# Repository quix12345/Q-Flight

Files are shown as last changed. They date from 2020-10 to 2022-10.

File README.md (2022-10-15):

# Q-Flight Quadrotor

#### Descirpition
Q-Flight is a fully functional quadrotor system which was based on STM32 F411 & FreeRTOS. It includes the flight controller, ground station, Unity simulations and 3D printing model...

#### Q-Flight Overview

Q-Flight was the last project I've done in my high school times. It include the remote controller, flight control system based on STM32 F4, and related softwares... Click the video and see what Q-Flight got ! 
Video Download: [link](https://github.com/quix12345/Q-Flight/blob/master/qflight/quadrotor.mp4)
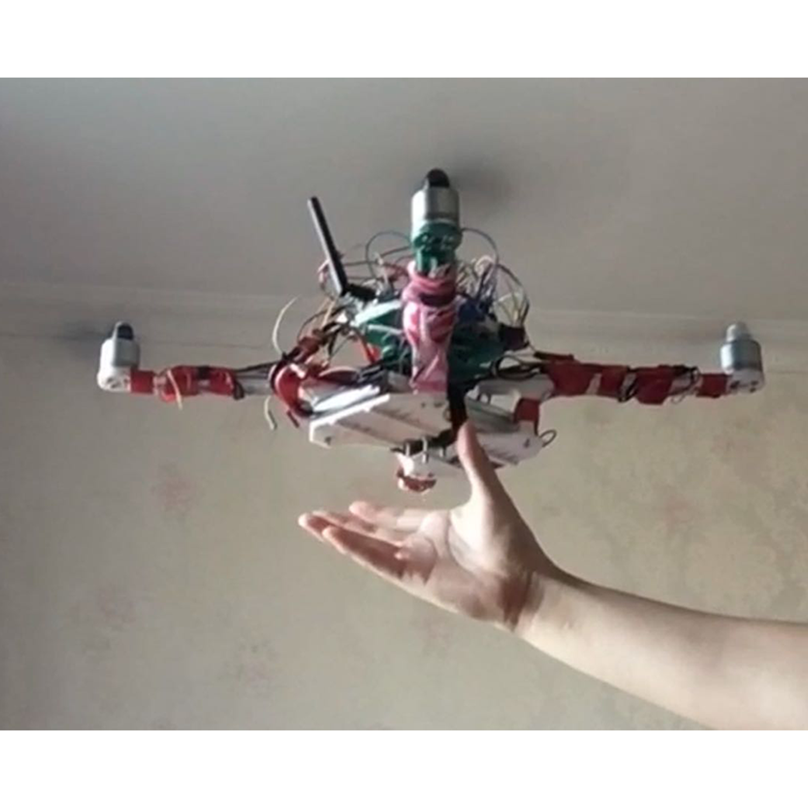
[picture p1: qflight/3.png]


#### Flight Controller

For the Q-Flight controller, a range of sensors was used, for instance the barometer and GPS are combined for the navigation and position control in outdoor, while laser lidar and optical flow sensor was responsible for the indoor positioning. By using Mahony algorithm as the core for calculating the attitude of the quadrotor from accelerometer and gyroscope, thus the internal Strapdown Inertia Navigation System will gain sufficient infomation to control its altitude and position. FreeRTOS is also used to make the whole system run at a higher speed. In addition to the core control system, GNSS and GPRS are also added to send back flight data to the back-end server through socket to monitor the flight even in case of remote control failure. 

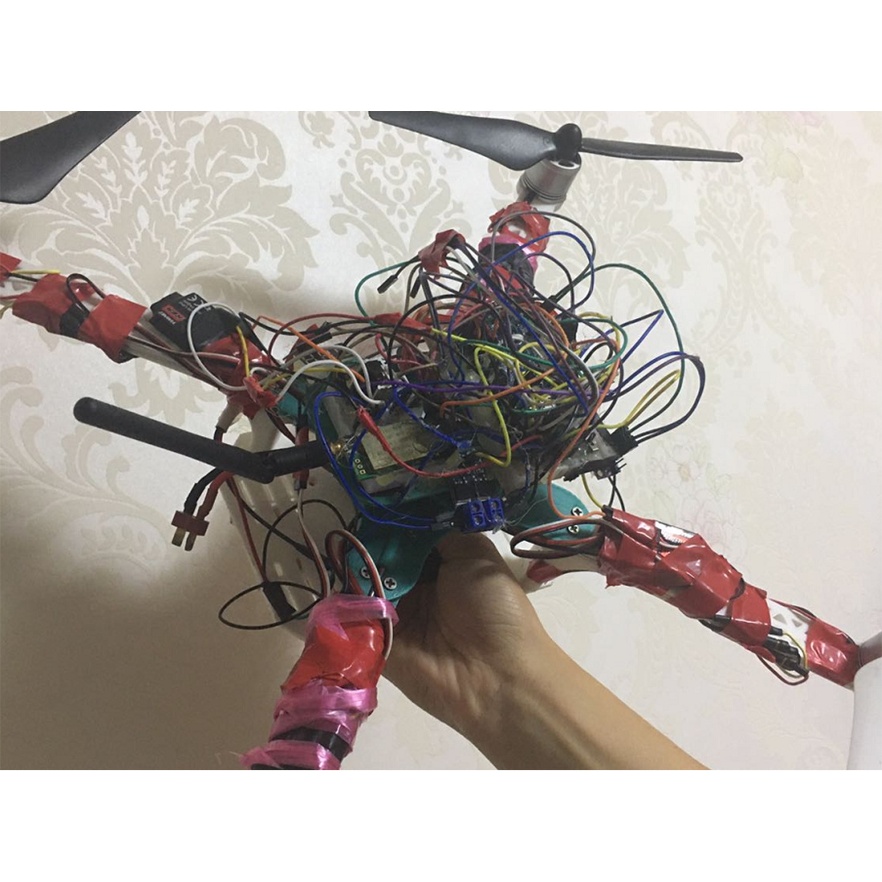
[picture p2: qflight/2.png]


#### Remote Control

The Remote Control use implemented by using wireless USART through LORA protocols which has achieve over  2100km as its valid remote control distance through air. The Q-Flight remote communication protocol supports the control of the quadrotor, transporting the quadrotor's status, change values in Flash, customize PID controllers, transmitting large amount of information, sensor calibration, etc. The protocol received by quadrotor starts with '0xC8' and end with '0xC9' , while the protocol received by the ground staion was start with double  '0xC8' and end with double '0xC9'. The hardware and coding system was proved to be highly reliable during several tests in Q-Flight.

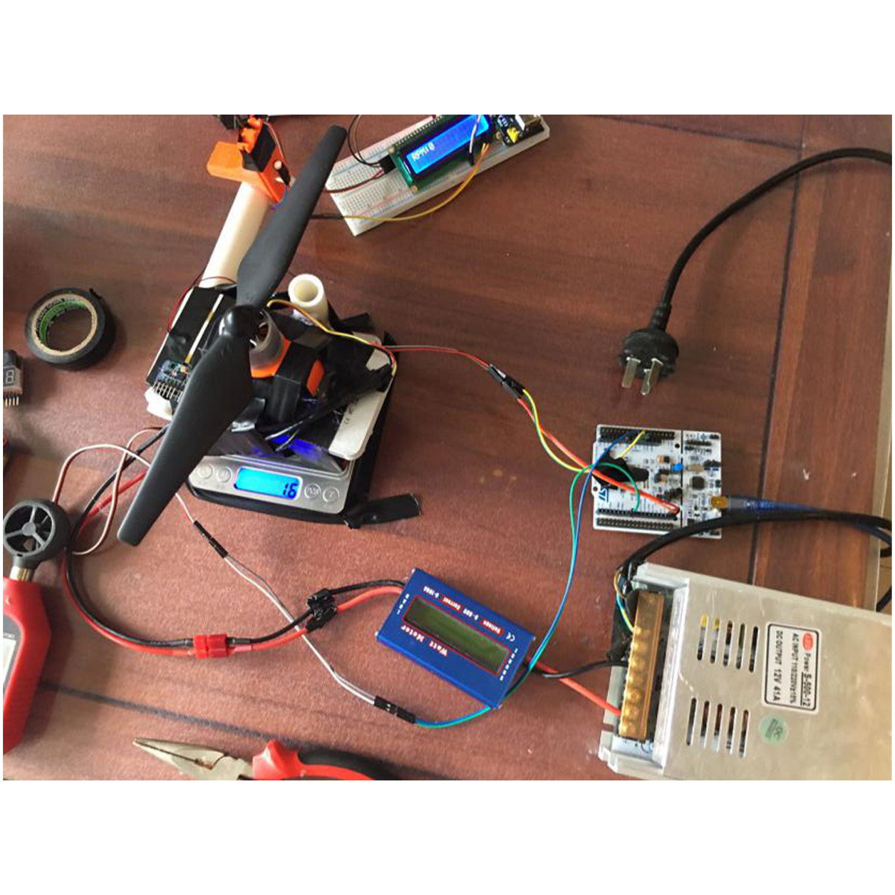
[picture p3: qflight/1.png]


#### 3D Printing Model

The framework support the whole quadrotor was made from 3D printing and some steel stick to enhance some of the core part. This enables me manufacturing Q-Flight at a very lost cost. But the time it took to make one was too long and the hardness are not as good as the framework we can buy on the internet. It still need to be improved. 

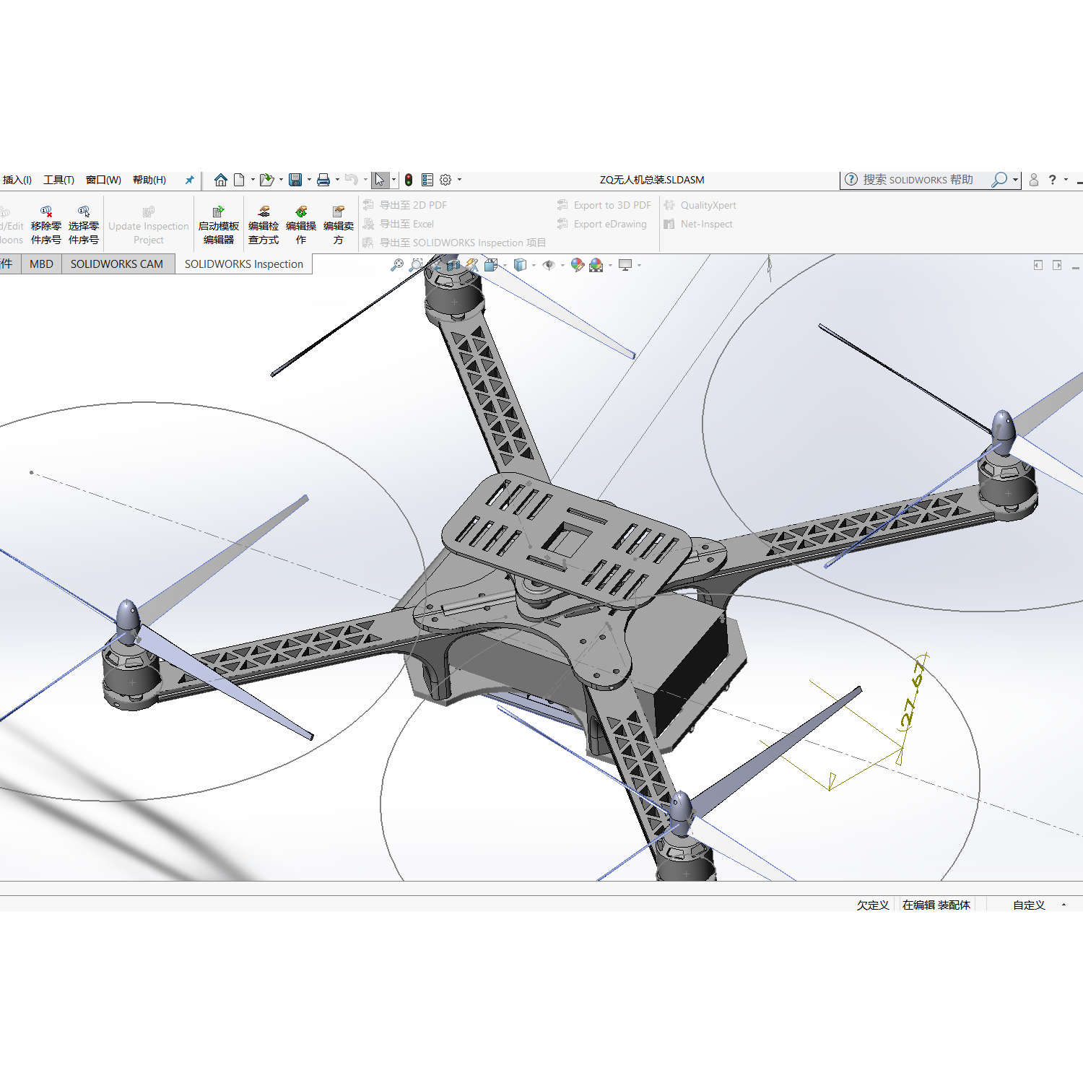
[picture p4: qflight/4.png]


#### Pyqt5 Based Ground Station Software

The ground station software provides a powerful tool to manage and control Q-Flight. It enables the developer to monitor the real-time status of Q-Flight directly and change the values for PID and other settings in Flash easily. It include the Opengl support the visualization of the attitude of Q-Flight and pyqt-graph to show the variation in diffierent status magnitudes. The GPS and GSM functionalities are currently developing now.

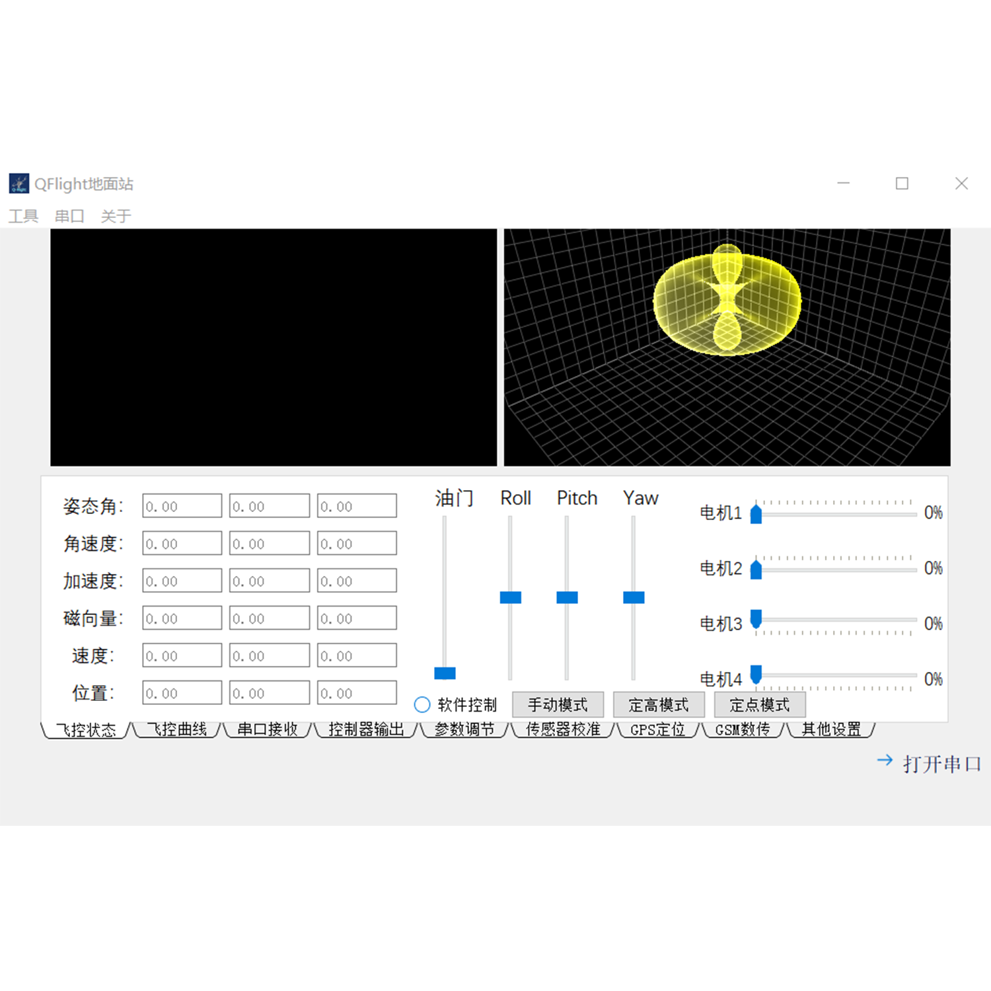
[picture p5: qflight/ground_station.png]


#### Furture Plans

I will implement remote control through LTE 4G, try to use an extended Kalman Filter and other control algorithm by using a MCU supporting Linux. Also the PCB version of the flight controller is on its way...

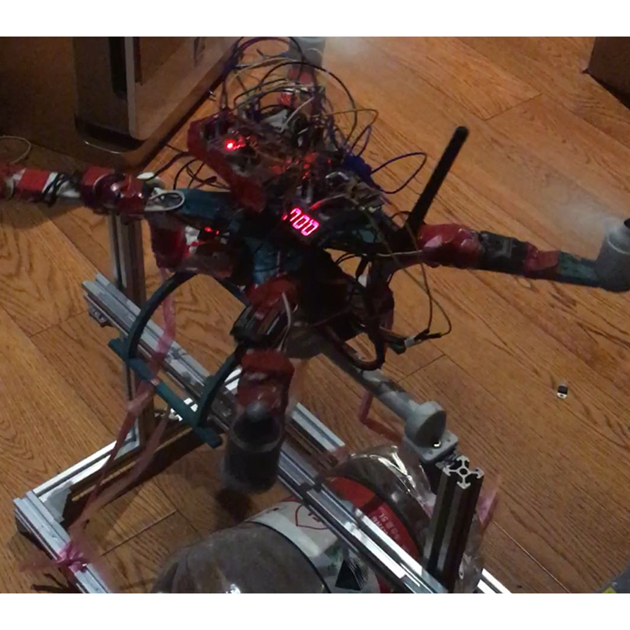
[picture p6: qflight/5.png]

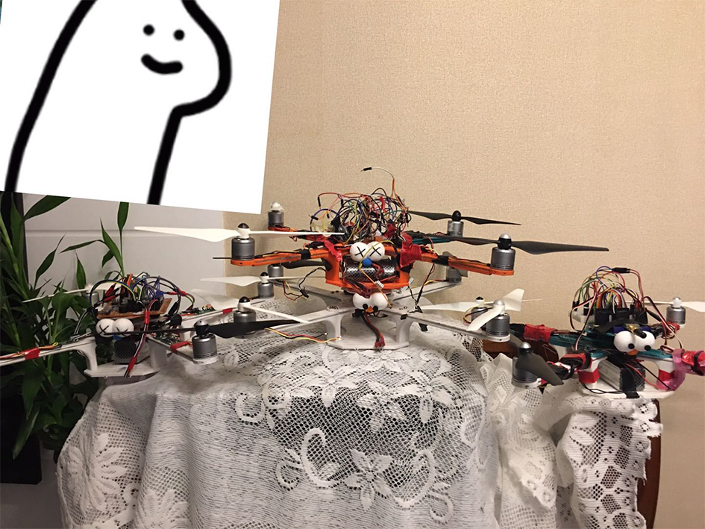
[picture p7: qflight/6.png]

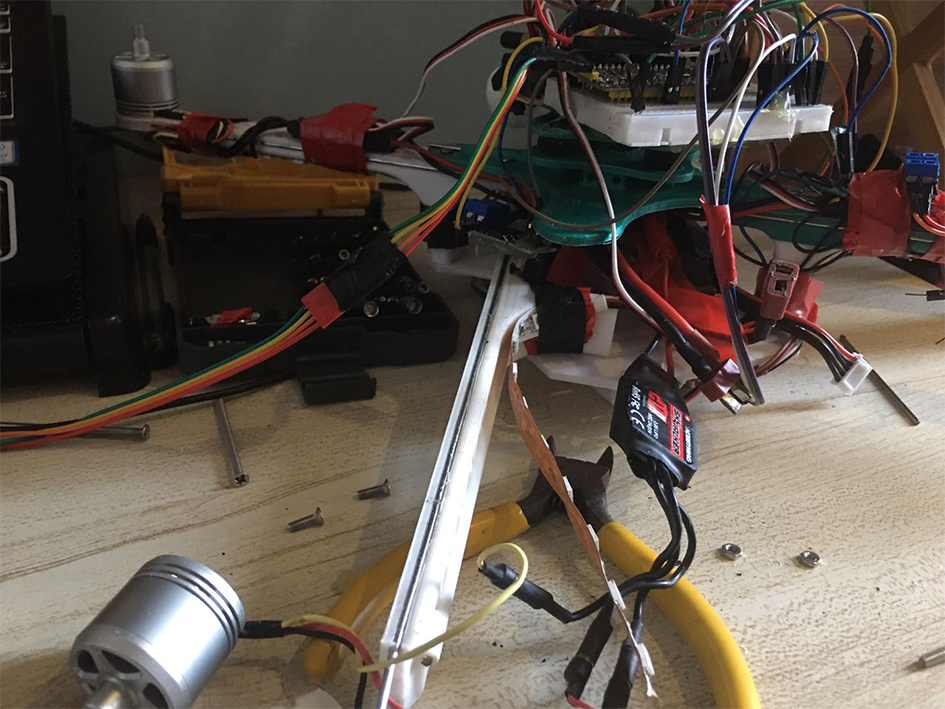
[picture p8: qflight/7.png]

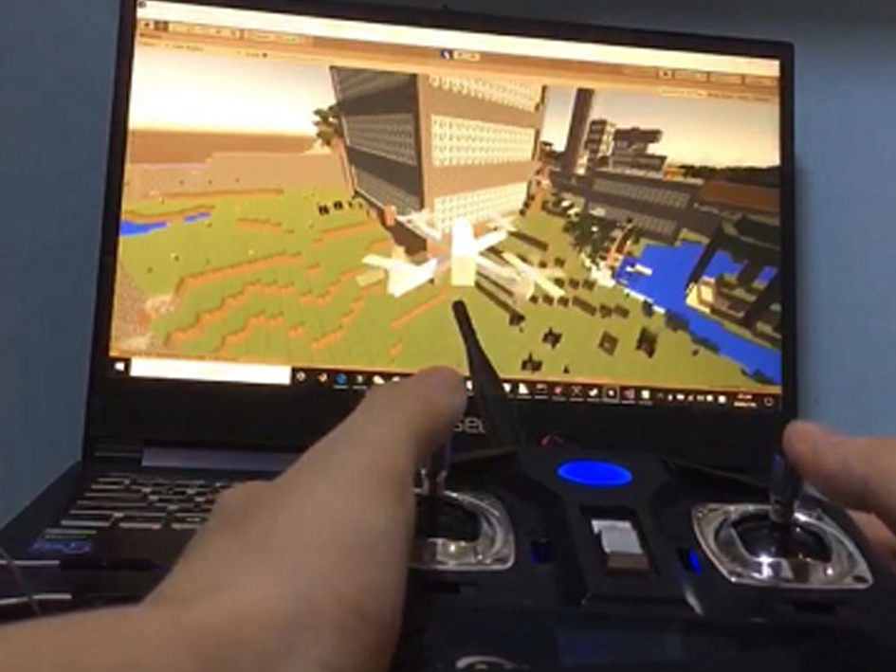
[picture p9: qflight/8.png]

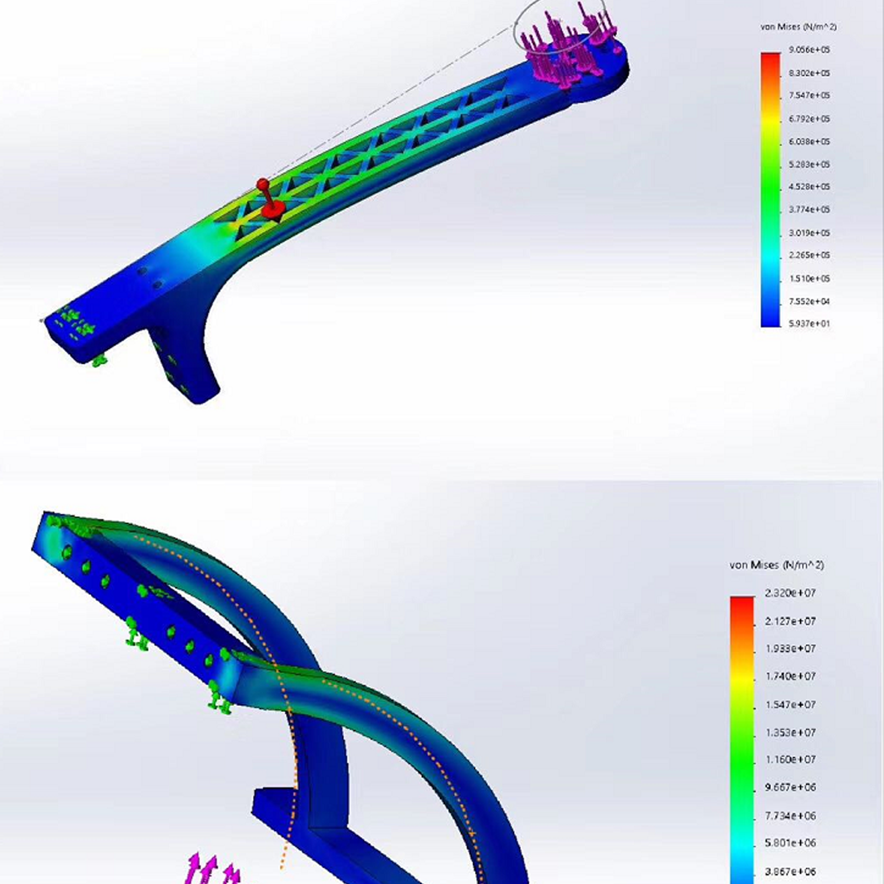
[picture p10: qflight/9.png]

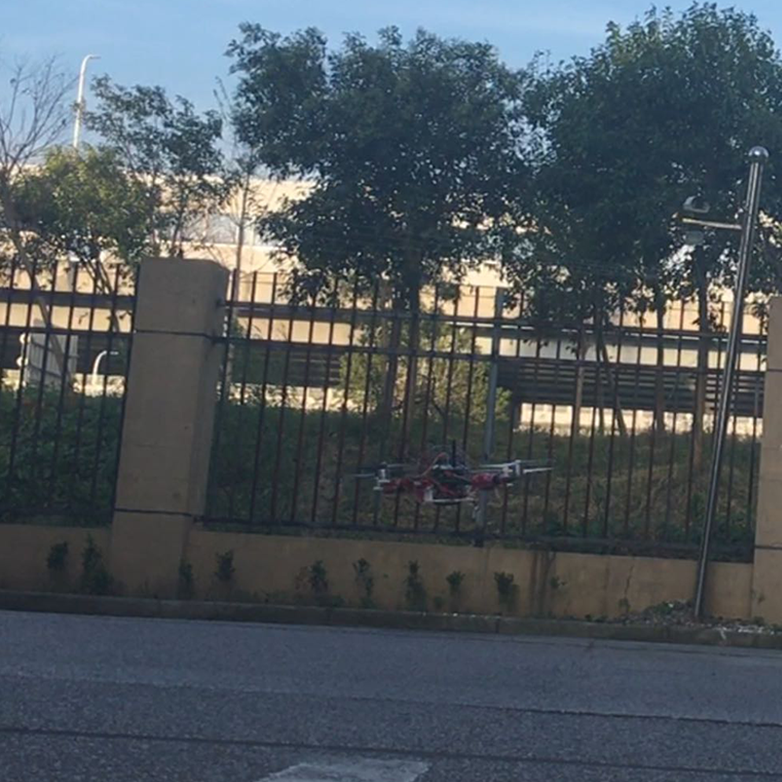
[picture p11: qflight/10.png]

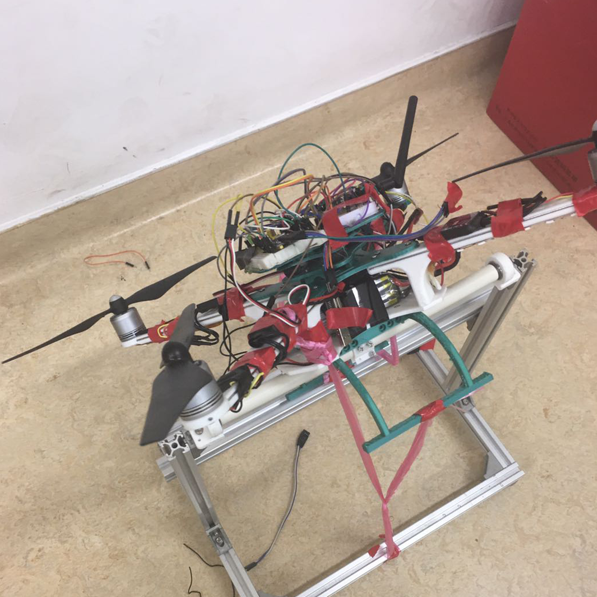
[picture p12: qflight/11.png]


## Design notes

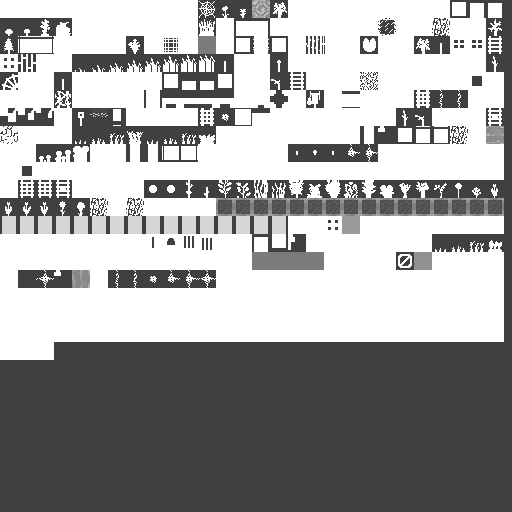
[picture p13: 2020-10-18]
Unity/Assets/MC/sizifen-Alpha.png

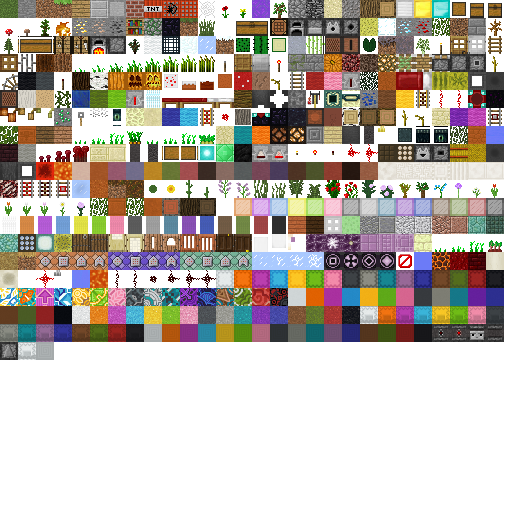
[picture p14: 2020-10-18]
Unity/Assets/MC/sizifen-RGBA.png

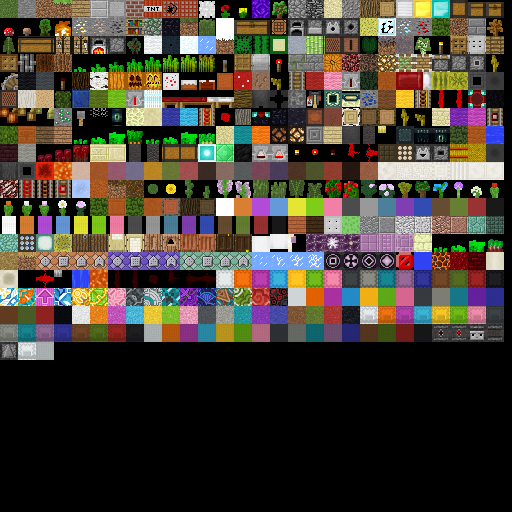
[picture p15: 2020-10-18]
Unity/Assets/MC/sizifen-RGB.png

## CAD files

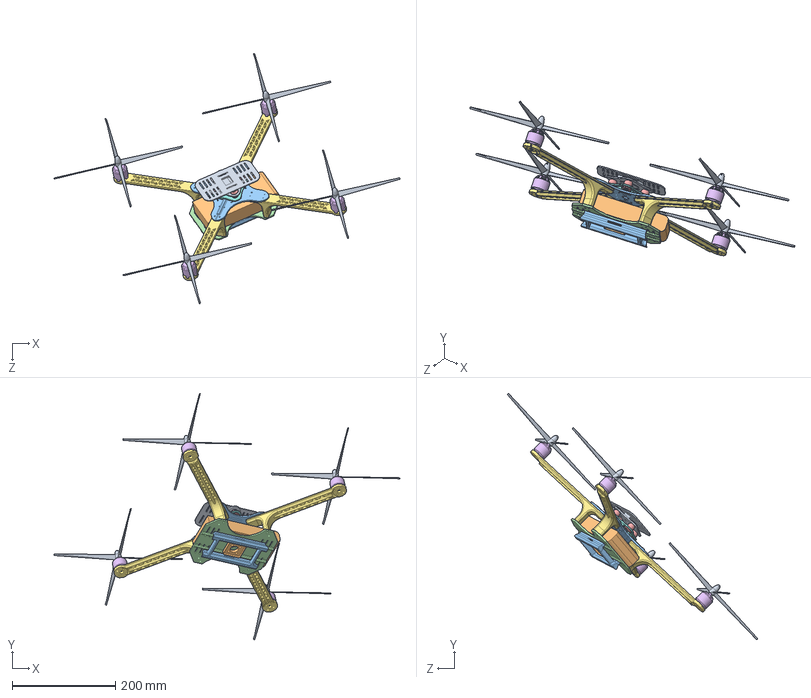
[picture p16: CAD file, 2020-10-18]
Models/Q-Flight version1/ZQ无人机总装.SLDASM
669.7 x 477.1 x 484.9 mm
电池
航电系统座
核心板
减震球 x 4
2312电机 x 4
2312圆形电机臂 x 4
减震台底座
航电系统座 - 顶部
光学吊舱
平面起落架

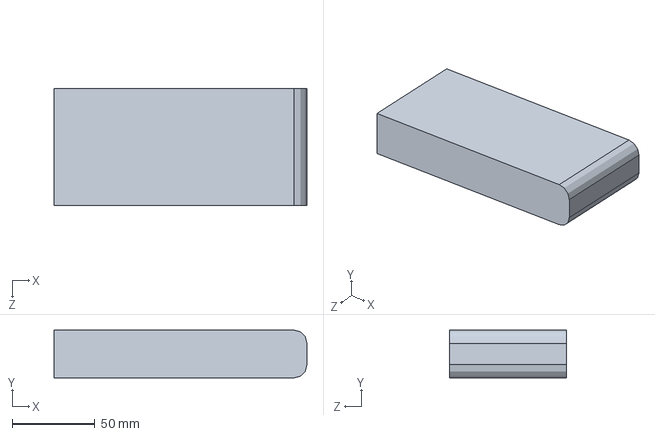
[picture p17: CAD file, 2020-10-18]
Models/Q-Flight version1/电池.SLDPRT
153.0 x 29.0 x 71.0 mm

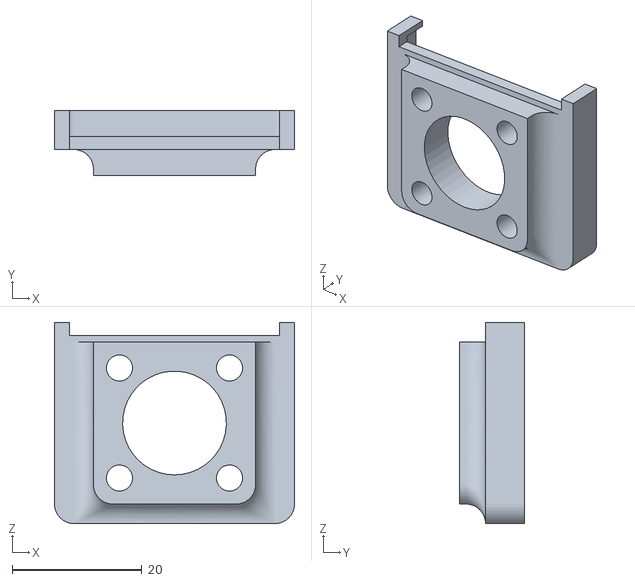
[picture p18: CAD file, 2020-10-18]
Models/STL/guang_xue_diao_cang.STL
37.0 x 10.0 x 31.0

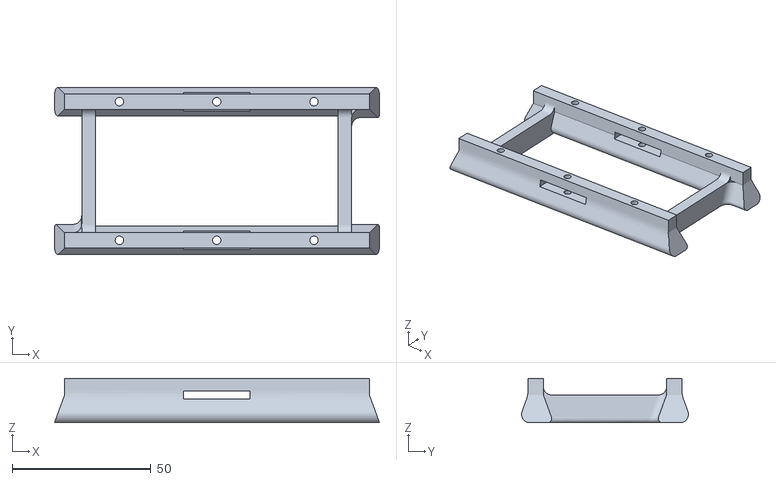
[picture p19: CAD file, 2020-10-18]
Models/STL/pingmian_qiluojia.STL
117.3 x 60.3 x 16.0

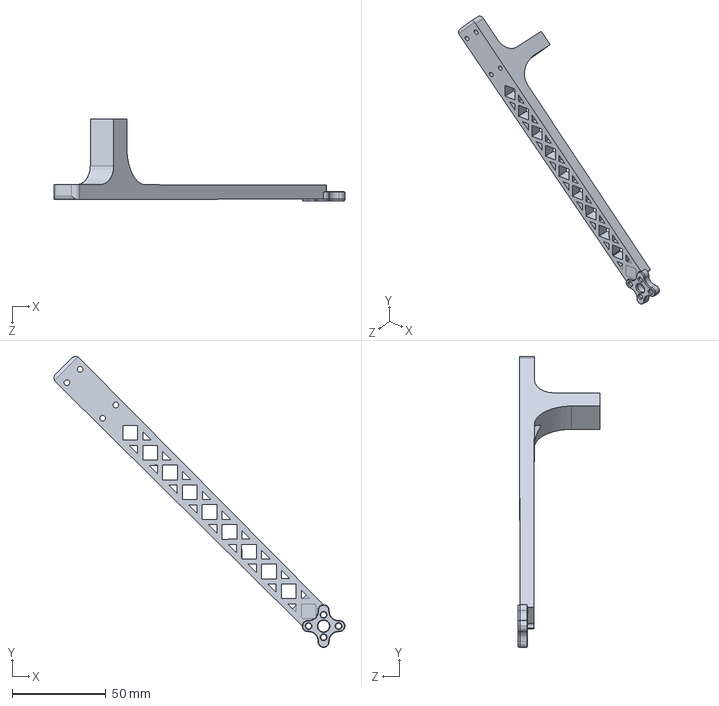
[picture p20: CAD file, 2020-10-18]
Models/Q-Flight version1/电机座.SLDPRT
155.4 x 155.4 x 43.7 mm

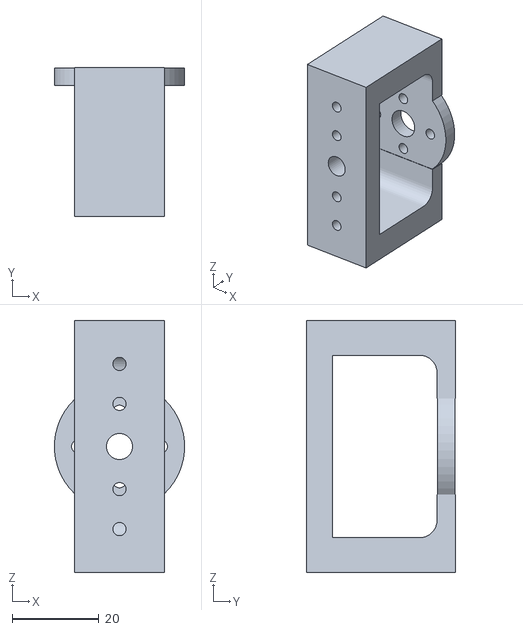
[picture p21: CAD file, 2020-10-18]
Models/STL/2312圆形电机座.STL
29.9 x 34.2 x 58.0

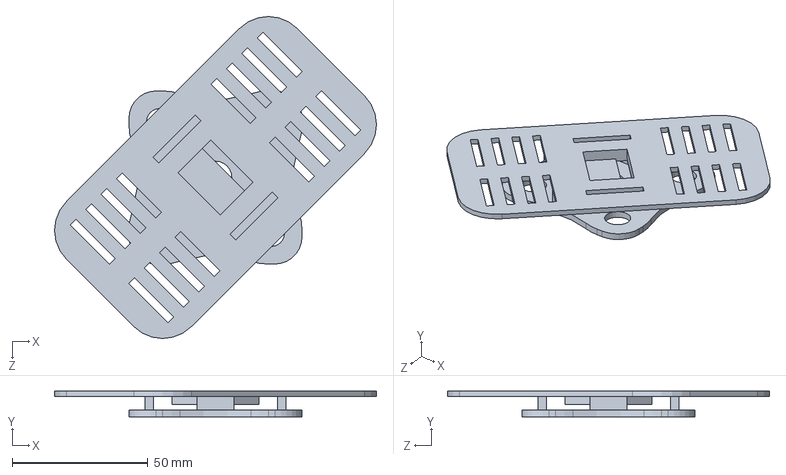
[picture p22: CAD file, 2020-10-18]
Models/Q-Flight version1/航电系统座 - 顶部.SLDPRT
118.4 x 9.50 x 118.4 mm

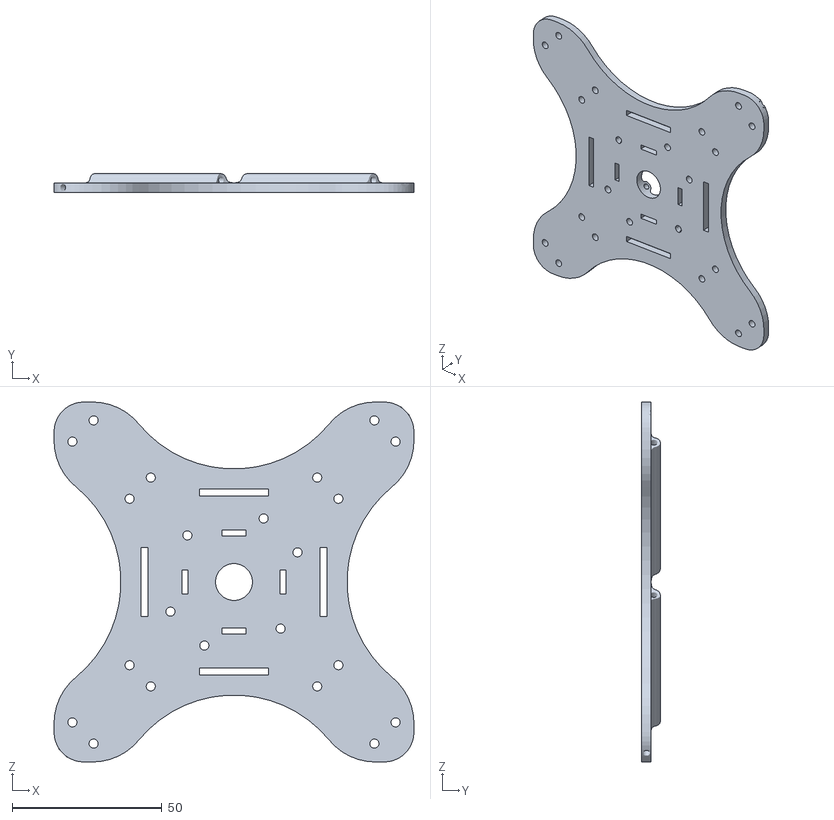
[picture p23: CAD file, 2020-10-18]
Models/STL/航电系统座2.STL
120.2 x 6.25 x 120.2

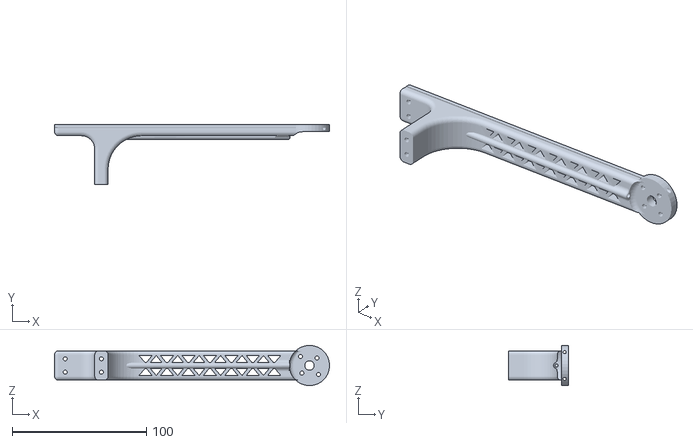
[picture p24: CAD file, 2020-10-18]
Models/STL/2312圆形电机臂new.STL
205.1 x 45.0 x 29.9

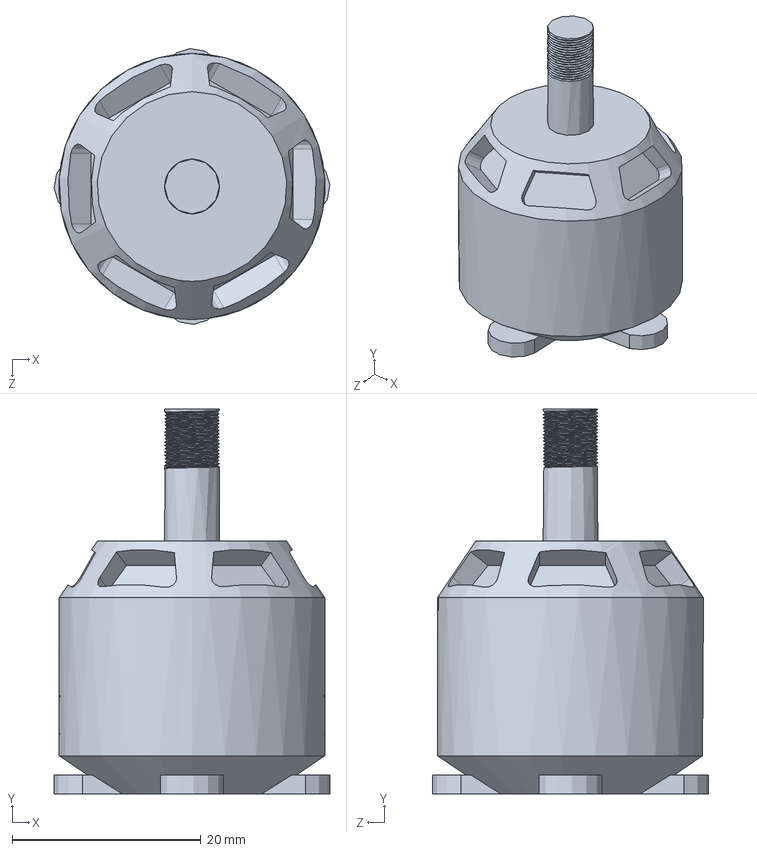
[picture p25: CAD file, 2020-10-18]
Models/Q-Flight version1/2312电机.SLDPRT
29.2 x 40.8 x 29.2 mm

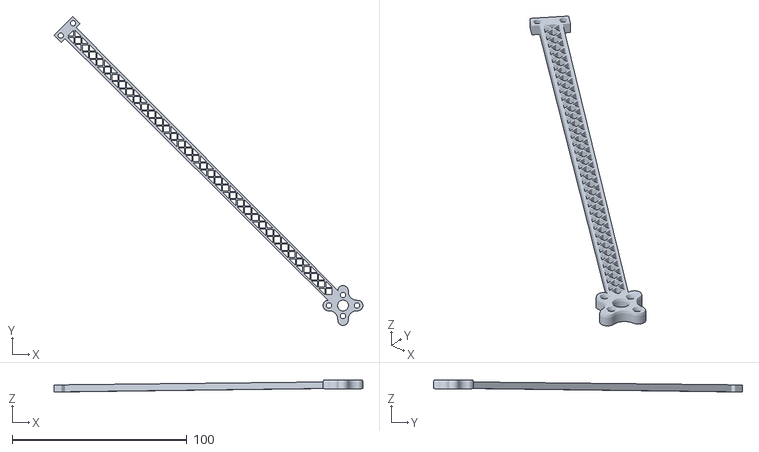
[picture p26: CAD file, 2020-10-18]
Models/STL/电机臂.STL
176.8 x 176.8 x 6.71

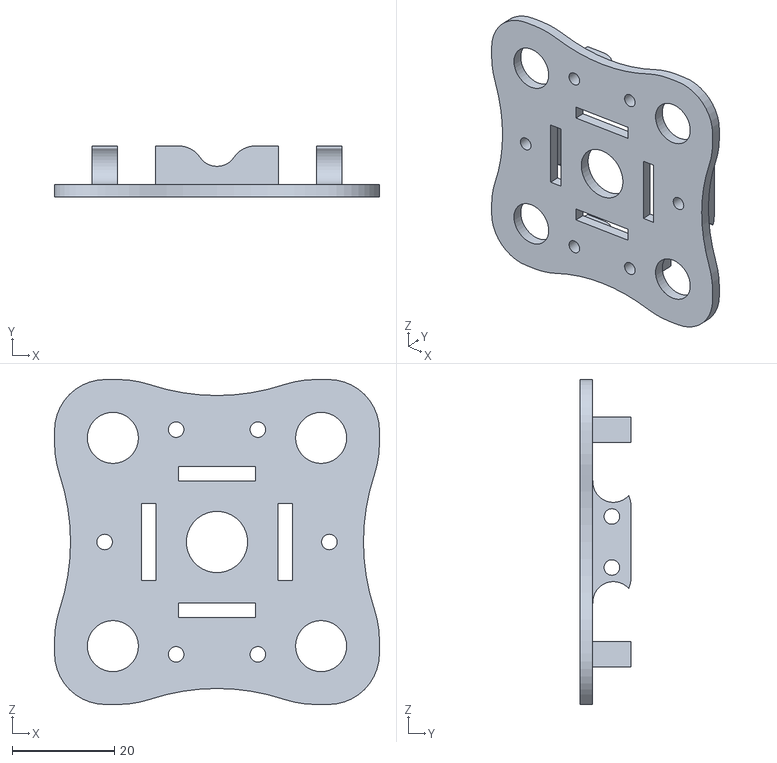
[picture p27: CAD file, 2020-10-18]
Models/STL/减震台底座.STL
63.6 x 10.0 x 63.6

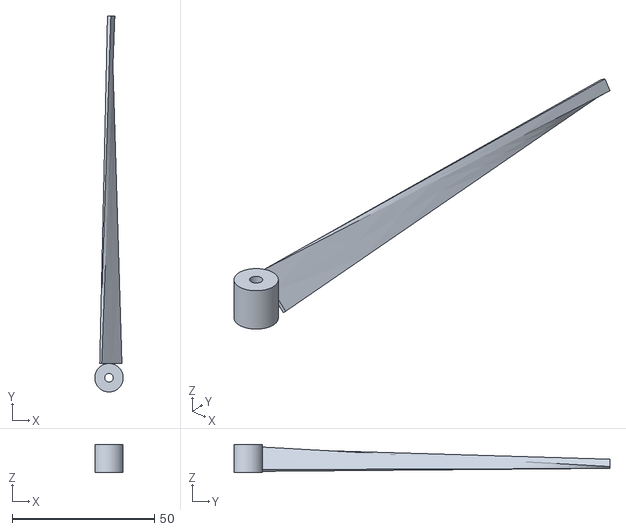
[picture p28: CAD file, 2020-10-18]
Models/STL/1047-2.STL
10.0 x 132.0 x 10.0

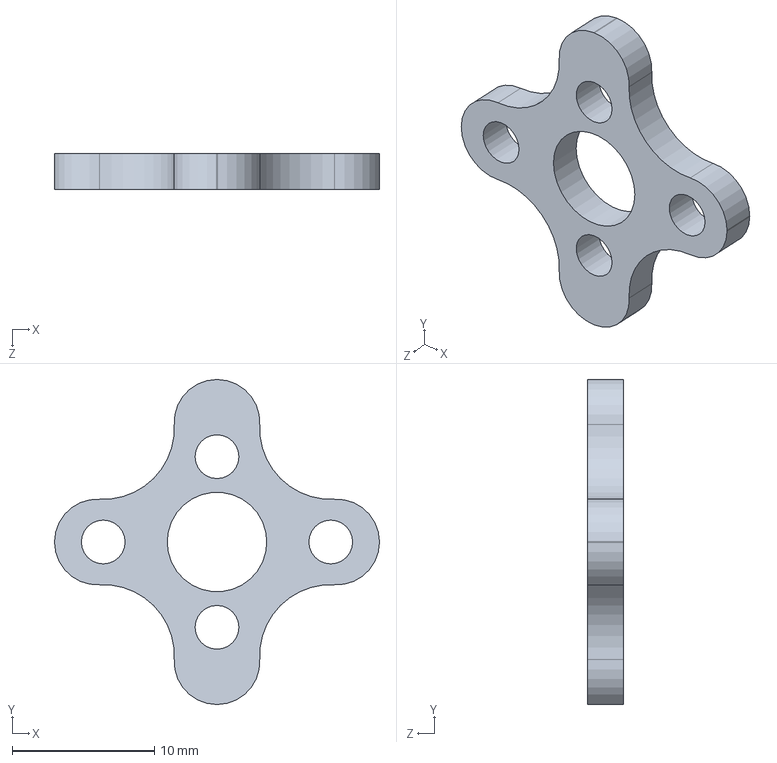
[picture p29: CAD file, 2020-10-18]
Models/Q-Flight version1/电机座 - 16x12.SLDPRT
22.9 x 22.9 x 2.50 mm

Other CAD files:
Models/Q-Flight version1/航电系统座.SLDPRT
Models/Q-Flight version1/减震台底座.SLDPRT
Models/STL/核心板.STL
Models/Q-Flight version1/减震球.SLDPRT
Models/Q-Flight version1/1047.SLDPRT
Models/Q-Flight version1/2312圆形电机座.SLDPRT
Models/Q-Flight version1/2312圆形电机臂.SLDPRT
Models/Q-Flight version1/ZQ无人机总装 - 副本.SLDASM
Models/Q-Flight version1/光学吊舱.SLDPRT
Models/Q-Flight version1/平面起落架.SLDPRT
Models/Q-Flight version1/核心板.SLDPRT
Models/Q-Flight version1/电机座 - 副本.SLDPRT
Models/Q-Flight version1/航电系统.SLDPRT
Models/Q-Flight version1/航电系统座_顶部.SLDPRT
Models/Q-Flight version1/起落架.SLDPRT
Models/Q-Flight version1/零件3.SLDPRT
Models/STL/2312圆形电机测试座.STL
Models/STL/电机座.STL
Models/STL/航电系统座 - 顶部2.STL
Models/STL/起落架.STL

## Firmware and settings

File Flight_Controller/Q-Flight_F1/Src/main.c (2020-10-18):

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

/* Includes ------------------------------------------------------------------*/
#include "main.h"
#include "i2c.h"
#include "tim.h"
#include "usart.h"
#include "gpio.h"


/* USER CODE BEGIN PV */
uint8_t content[UART_CONTENT_BUFFER_SIZE];
uint8_t Uart_Flag,LC306_Uart_Flag=0;
float pitch_offset=0;
float roll_offset=0;
float control_max_angle=15;
int verbose=0;
uint8_t Light_Toggle;
int num_of_commands,num_of_success_commands;
float quad_control_period=30;
uint8_t Control_Mode=MANUAL_MODE;
extern quadstate_t target_state,current_state;
/* USER CODE END PV */

void SystemClock_Config(void);
/**
  * @brief  The application entry point.
  * @retval int
  */
int main(void)
{
  /* MCU Configuration--------------------------------------------------------*/

  /* Reset of all peripherals, Initializes the Flash interface and the Systick. */
  HAL_Init();

  /* Configure the system clock */
  SystemClock_Config();

  /* Initialize all configured peripherals */
  MX_GPIO_Init();
  MX_I2C1_Init();
  MX_TIM1_Init();
  MX_TIM2_Init();
  MX_USART2_UART_Init();
  MX_USART3_UART_Init();
  /* USER CODE BEGIN 2 */
	quad_control_period=htim2.Init.Period/1000;
//	LC306_Config_Init_Uart();
//	current_state.position.z=30;
//	while(1){
//	
//	}
	MPU9250_Init();
	//必须先初始化Mpu6050！！！！
	Flash_Setting_Init(); 
	PWN_Init(htim1);
	// PWN_Calibrate_all(htim1);
	printf("Initing...\r\n");
	AHRS_Date_Init();
	PID_ControllerInit();
	SensorInit();
	printf("ok\r\n");
	//开启遥控器中断
	LL_USART_EnableIT_RXNE(REMOTER_USART);   
	LL_USART_EnableIT_PE(REMOTER_USART);
	
	//指示初始化完成
	Work_Indicate(0);
	HAL_TIM_Base_Init(&htim2);
	HAL_TIM_Base_Start_IT(&htim2);
	//MX_IWDG_Init();
  /* USER CODE END 2 */

  /* Infinite loop */
  /* USER CODE BEGIN WHILE */
  while (1)
  {
//			vl5310x_Update();
//		printf("%.2f\r\n",laser_height);
    /* USER CODE END WHILE */

    /* USER CODE BEGIN 3 */
  }
  /* USER CODE END 3 */
}

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
/* USER CODE BEGIN 4 */
int fputc(int ch, FILE *f) // ???????
{
	uint8_t temp=ch;
	while (!LL_USART_IsActiveFlag_TXE(REMOTER_USART));
	LL_USART_TransmitData8(REMOTER_USART,temp); 
	while (!LL_USART_IsActiveFlag_TC(REMOTER_USART));
	return 0;
}


void HAL_TIM_PeriodElapsedCallback(TIM_HandleTypeDef *htim)
{
   if (htim == (&htim2))
   {
		
	  Attitude_Update(); // 更新姿态信息
		if(Control_Mode!=REPORT_ONLY_MODE&&Control_Mode!=MANUAL_MODE){
			Altitude_Estimate(); // 更新高度信息，位置由光流直接给出
		}
		Quad_Control();
//		 current_state.position.z=0.5;
//		printf("%.2f  %.2f  %.2f %d \r\n",current_state.position.z,current_state.position.x,current_state.position.y,LC306_Uart_Flag);
		Uart_Flag_Update();
//	HAL_IWDG_Refresh(&hiwdg);
   }
}
/* USER CODE END 4 */
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


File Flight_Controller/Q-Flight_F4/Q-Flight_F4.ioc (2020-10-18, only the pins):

Mcu.UserName=STM32F401CBUx
PA0-WKUP.Signal=S_TIM5_CH1
PA1.Signal=S_TIM5_CH2
PA10.Signal=S_TIM1_CH3
PA11.Signal=S_TIM1_CH4
PA13.Signal=SYS_JTMS-SWDIO
PA14.Signal=SYS_JTCK-SWCLK
PA2.Signal=USART2_TX
PA3.Signal=USART2_RX
PA8.Signal=S_TIM1_CH1
PA9.Signal=S_TIM1_CH2
PB1.GPIO_Label=US_ECHO
PB1.Signal=GPXTI1
PB10.GPIO_Label=Sensor_Power
PB10.Signal=GPIO_Output
PB13.GPIO_Label=MISS_FIRE
PB13.Signal=GPIO_Output
PB14.GPIO_Label=NIGHT_LED
PB14.Signal=GPIO_Output
PB15.GPIO_Label=WORK_INDICATE
PB15.Signal=GPIO_Output
PB2.GPIO_Label=US_TRIG
PB2.Signal=GPIO_Output
PB6.Signal=USART1_TX
PB7.Signal=USART1_RX
PB8.Signal=I2C1_SCL
PB9.Signal=I2C1_SDA

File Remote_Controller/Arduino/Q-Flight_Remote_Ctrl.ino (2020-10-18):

#include <LiquidCrystal_I2C.h>

#define TROTTLE A0
#define YAW A1
#define PITCH A2
#define ROLL A3
#define MAX_WAITING_TIME 20

#define FIRST_BTN 3
#define INDICATE_PIN 2

LiquidCrystal_I2C lcd(0x27, 16, 2);
int control_mode=1;
int throttle_old=0;
int yaw_old=0;
int pitch_old=0;
int roll_old=0;
long time=0;

int compare(int a,int b){
  if(abs(a-b)>3){
    return true;
  }
  return false;
}

void setup() {
  // put your setup code here, to run once:
  Serial.begin(115200);
   lcd.init();
  lcd.backlight();
  lcd.setCursor(2, 0);
  lcd.print("SYSTEM SETUP");
  lcd.setCursor(0, 1);
  lcd.print("--By Quix ZQWEI");
  delay(1500);
  lcd.clear();
  lcd.setCursor(0, 0);
  lcd.print("Remote Controller");
  pinMode(TROTTLE,INPUT);
  pinMode(YAW,INPUT);
  pinMode(PITCH,INPUT);
  pinMode(ROLL,INPUT);
   for(int i=0;i<4;i++){
    pinMode(i+FIRST_BTN,INPUT_PULLUP);
  }
  time=millis();
}

int clean_data(int input_value){
  if(abs(input_value-50)<=1){
    return 50;
  }
  return input_value;
}

void loop() {
  // put your main code here, to run repeatedly:
  int throttle=(float)analogRead(A0)/1024*100;
  int yaw=(float)analogRead(YAW)/1024*100;
  int pitch=(float)analogRead(PITCH)/1024*100;
  int roll=(float)analogRead(ROLL)/1024*100;

  yaw=clean_data(yaw);
  pitch=clean_data(pitch);
  roll=clean_data(roll);
  
  if(compare(throttle,throttle_old)||compare(yaw,yaw_old)||
  compare(pitch,pitch_old)||compare(roll,roll_old)||
  millis()-time>MAX_WAITING_TIME){
    time=millis();
    if(true){
    Serial.write(0xC8);
    Serial.write(0xC1);
    Serial.write(throttle+1);
    Serial.write(yaw+1);
    Serial.write(pitch+1);
    Serial.write(roll+1);
    uint16_t sum=throttle+yaw+pitch+roll+0xC8+0XC1+4;
    sum=sum&0x00FF;
    Serial.write(sum);
    Serial.write(0xC9);
    }
    else{
    Serial.print(throttle);
    Serial.print(",");
    Serial.print(yaw);
    Serial.print(",");
    Serial.print(pitch);
    Serial.print(",");
    Serial.print(roll);
    Serial.println();
    }
    throttle_old=throttle;
    yaw_old=yaw;
    pitch_old=pitch;
    roll_old=roll;
    delay(2);
  }

  for(int i=0;i<4;i++){
    if(digitalRead(i+FIRST_BTN)==LOW){
      switch(i){
        case 0:
//            Serial.write(0xC8);
//            Serial.write(0xC4);
//            Serial.write(0xCA);
//            Serial.write(31);
//            Serial.write(64);
//            Serial.write(181);
//            Serial.write(0xC9);

    Serial.write(200);
    Serial.write(196);
    Serial.write(203);
    Serial.write(87);
    Serial.write(201);
        break;
        case 1:
           Serial.write(0xC8);
            Serial.write(0xC4);
            Serial.write(0xC4);
            Serial.write(0x50);
            Serial.write(0xC9);
        break;
        case 2:
          if(control_mode==1){
            control_mode=2;
          }
          else{
            control_mode=1;
          }
            Serial.write(0xC8);
            Serial.write(0xC4);
            Serial.write(0xC7);
            Serial.write(control_mode);
            Serial.write(0x53+control_mode);
            Serial.write(0xC9);
        break;
        case 3:
            Serial.write(0xC8);
            Serial.write(0xC4);
            Serial.write(0xC7);
            Serial.write(0x01);
            Serial.write(0x54);
            Serial.write(0xC9);
        break;
        default:
        break;
      }
      while(digitalRead(i+FIRST_BTN)==LOW);
    }
  }
}

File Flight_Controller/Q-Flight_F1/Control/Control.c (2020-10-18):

#include "Control.h"

pidsuite pid_velocity_x,pid_velocity_y,pid_velocity_z; //速度环pid
pidsuite pid_position_x,pid_position_y,pid_position_z; //位置环pid
pidsuite pid_in_Pitch,pid_in_Roll,pid_in_Yaw;
pidsuite pid_out_Pitch,pid_out_Roll,pid_out_Yaw;
Vector3 previous_position;
Vector2f error_position;
quadstate_t target_state,current_state;
float dt;
float throttleLpf,throttleBase,throttle;
float pid_out_pitch=0;
float pid_out_roll=0;
float pid_out_yaw=0;
float pid_in_pitch=0;
float pid_in_roll=0;
float pid_in_yaw=0;
uint16_t pwm_moto1,pwm_moto2,pwm_moto3,pwm_moto4;   

void PID_ControllerInit(){
	//姿态控制器pid初始化
	pidInit(&pid_out_Pitch, 0, Flash2Float(Quad_Parameter[1]), Flash2Float(Quad_Parameter[2]), Flash2Float(Quad_Parameter[3]));
	pidInit(&pid_out_Roll, 0, Flash2Float(Quad_Parameter[4]), Flash2Float(Quad_Parameter[5]), Flash2Float(Quad_Parameter[6]));
	pidInit(&pid_out_Yaw, 0, Flash2Float(Quad_Parameter[7]), Flash2Float(Quad_Parameter[8]), Flash2Float(Quad_Parameter[9]));
	
	pidInit(&pid_in_Pitch, 0, Flash2Float(Quad_Parameter[10]), Flash2Float(Quad_Parameter[11]), Flash2Float(Quad_Parameter[12]));
  pidInit(&pid_in_Roll, 0, Flash2Float(Quad_Parameter[13]), Flash2Float(Quad_Parameter[14]), Flash2Float(Quad_Parameter[15]));
	pidInit(&pid_in_Yaw,0, Flash2Float(Quad_Parameter[16]),Flash2Float(Quad_Parameter[17]),Flash2Float(Quad_Parameter[18]));

	pidSetIntegralLimit(&pid_out_Pitch, Quad_Parameter[19]);
	pidSetIntegralLimit(&pid_out_Roll, Quad_Parameter[20]);
	pidSetIntegralLimit(&pid_out_Yaw, Quad_Parameter[21]);
  pidSetIntegralLimit(&pid_in_Pitch, Quad_Parameter[22]);
	pidSetIntegralLimit(&pid_in_Roll, Quad_Parameter[23]);
	pidSetIntegralLimit(&pid_in_Yaw, Quad_Parameter[24]);
	
	
//	pidInit(&pid_out_Pitch, 0, PID_OUT_PITCH_KP, PID_OUT_PITCH_KI, PID_OUT_PITCH_KD);
//	pidInit(&pid_out_Roll, 0, PID_OUT_ROLL_KP, PID_OUT_ROLL_KI, PID_OUT_ROLL_KD);
//	
//	pidInit(&pid_in_Pitch, 0, PID_IN_PITCH_KP, PID_IN_PITCH_KI, PID_IN_PITCH_KD);
//  pidInit(&pid_in_Roll, 0, PID_IN_ROLL_KP, PID_IN_ROLL_KI, PID_IN_ROLL_KD);
//	pidInit(&pid_in_Yaw,0,PID_IN_YAW_KP,PID_IN_YAW_KI,PID_IN_YAW_KD);

//	pidSetIntegralLimit(&pid_out_Pitch, PID_OUT_PITCH_INTEGRATION_LIMIT);
//	pidSetIntegralLimit(&pid_out_Roll, PID_OUT_ROLL_INTEGRATION_LIMIT);
//  pidSetIntegralLimit(&pid_in_Pitch, PID_IN_PITCH_INTEGRATION_LIMIT);
//	pidSetIntegralLimit(&pid_in_Roll, PID_IN_ROLL_INTEGRATION_LIMIT);
//	pidSetIntegralLimit(&pid_in_Yaw, PID_IN_YAW_INTEGRATION_LIMIT);
//	uint8_t index_offset=24;
//	pidInit(&pid_velocity_x, 0, Flash2Float(Quad_Parameter[1+index_offset+index_offset]), Flash2Float(Quad_Parameter[2+index_offset]), Flash2Float(Quad_Parameter[3+index_offset]));
//	pidInit(&pid_velocity_y, 0, Flash2Float(Quad_Parameter[4+index_offset+index_offset]), Flash2Float(Quad_Parameter[5+index_offset]), Flash2Float(Quad_Parameter[6+index_offset]));
//	pidInit(&pid_velocity_z, 0, Flash2Float(Quad_Parameter[7+index_offset+index_offset]), Flash2Float(Quad_Parameter[8+index_offset]), Flash2Float(Quad_Parameter[9+index_offset]));
//	
//	pidInit(&pid_position_x, 0, Flash2Float(Quad_Parameter[10+index_offset]), Flash2Float(Quad_Parameter[11+index_offset]), Flash2Float(Quad_Parameter[12+index_offset]));
//  pidInit(&pid_position_y, 0, Flash2Float(Quad_Parameter[13+index_offset]), Flash2Float(Quad_Parameter[14+index_offset]), Flash2Float(Quad_Parameter[15+index_offset]));
//	pidInit(&pid_position_z,0, Flash2Float(Quad_Parameter[16+index_offset]),Flash2Float(Quad_Parameter[17+index_offset]),Flash2Float(Quad_Parameter[18+index_offset]));

//	pidSetIntegralLimit(&pid_velocity_x, Quad_Parameter[19+index_offset]);
//	pidSetIntegralLimit(&pid_velocity_y, Quad_Parameter[20+index_offset]);
//	pidSetIntegralLimit(&pid_velocity_z, Quad_Parameter[21+index_offset]);
//  pidSetIntegralLimit(&pid_position_x, Quad_Parameter[22+index_offset]);
//	pidSetIntegralLimit(&pid_position_y, Quad_Parameter[23+index_offset]);
//	pidSetIntegralLimit(&pid_position_z, Quad_Parameter[24+index_offset]);
	
	//位置&速度控制器pid初始化
	pidInit(&pid_velocity_x, 0, PID_VELOCITY_X_KP, PID_VELOCITY_X_KI, PID_VELOCITY_X_KD);
	pidInit(&pid_velocity_y, 0, PID_VELOCITY_Y_KP, PID_VELOCITY_Y_KI, PID_VELOCITY_Y_KD);
	pidInit(&pid_velocity_z, 0, PID_VELOCITY_Z_KP, PID_VELOCITY_Z_KI, PID_VELOCITY_Z_KD);
	
	pidInit(&pid_position_x, 0, PID_POSITION_X_KP, PID_POSITION_X_KI, PID_POSITION_X_KD);
  pidInit(&pid_position_y, 0, PID_POSITION_Y_KP, PID_POSITION_Y_KI, PID_POSITION_Y_KD);
	pidInit(&pid_position_z, 0, PID_POSITION_Z_KP, PID_POSITION_Z_KI, PID_POSITION_Z_KD);

	pidSetIntegralLimit(&pid_velocity_x, PID_VELOCITY_X_INTEGRATION_LIMIT);
	pidSetIntegralLimit(&pid_velocity_y, PID_VELOCITY_Y_INTEGRATION_LIMIT);
	pidSetIntegralLimit(&pid_velocity_z, PID_VELOCITY_Z_INTEGRATION_LIMIT);
  pidSetIntegralLimit(&pid_position_x, PID_POSITION_X_INTEGRATION_LIMIT);
	pidSetIntegralLimit(&pid_position_y, PID_POSITION_Y_INTEGRATION_LIMIT);
	pidSetIntegralLimit(&pid_position_z, PID_POSITION_Z_INTEGRATION_LIMIT);
	
	Quadstate_Init(&target_state);
	Quadstate_Init(&current_state);
	Vector3_Init(&previous_position);
	Vector2f_Init(&error_position);
	dt=quad_control_period/1000;
}

void Get_current_state(){
	previous_position=current_state.position;
	
	current_state.attitude.roll=euler_angles[0];
	current_state.attitude.pitch=euler_angles[1];
	current_state.attitude.yaw=euler_angles[2];
	if(Control_Mode!=REPORT_ONLY_MODE&&Control_Mode!=MANUAL_MODE){
		// 注意光流位置信息的对应关系！
		current_state.position.y=opt_position_data.x;
		current_state.position.x=opt_position_data.y;
		current_state.position.z=calc_height;
		
		// 计算运动速度
		current_state.velocity.x=(current_state.position.x-previous_position.x)/dt;
		current_state.velocity.y=(current_state.position.y-previous_position.y)/dt;
		current_state.velocity.z=(current_state.position.z-previous_position.z)/dt;
	}
//	current_state.acc.x=accData[0];
//	current_state.acc.y=accData[1];
//	current_state.acc.z=accData[2];
	current_state.gyro.x=gyroData[0];
	current_state.gyro.y=gyroData[1];
	current_state.gyro.z=gyroData[2];
//	current_state.mag.x=gyroData[0];
//	current_state.mag.y=gyroData[1];
//	current_state.mag.z=gyroData[2];
}
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

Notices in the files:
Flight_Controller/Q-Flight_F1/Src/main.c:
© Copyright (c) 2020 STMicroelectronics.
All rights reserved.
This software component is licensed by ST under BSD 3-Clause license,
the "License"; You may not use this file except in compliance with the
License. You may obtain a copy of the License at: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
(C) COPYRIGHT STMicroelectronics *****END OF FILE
